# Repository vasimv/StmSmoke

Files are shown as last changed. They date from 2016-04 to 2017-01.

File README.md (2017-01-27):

This is open-source STM32F373C8T6 based vaping mod. Everything is under GPL license (see LICENSE file).

Output power is up to 140 Watts (although you may need a cooler for FETs). 

Schematics and PCB gerber files in the PCB subdirectory. Soon there will be another PCB variant (with
the coil inductor, which stabilizes output power and up to 10000 temperature measures per second). It
is very recommended to use 4-layers PCB with ground plane filled in the middle (otherwise you may get
crosstalk to touch sensors).

The screen is 128x64 OLED 0.96" screen ($4 or so on aliexpress).

Other directories is Ecliplse Mars + GCC/ARM project. There is a lot of crap generated by
STM32CubeMX, main files is:

 include/smoke.h (important stuff, check before compile!)
 src/smoke.c (main code)

The project uses the u8glib library to interface with the screen ( https://github.com/olikraus/u8glib ).

Note, new version uses FDV304P p-fet as additional output MOSFET driver and inverted PWM output, will not
work with older hadrware (comment #define INVERTED_PWM_COIL in smoke.h)!

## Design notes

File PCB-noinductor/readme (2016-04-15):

PCB gerber files. Non-mirrored, non-inverted!

Schematics in the StmSmoke.png file.

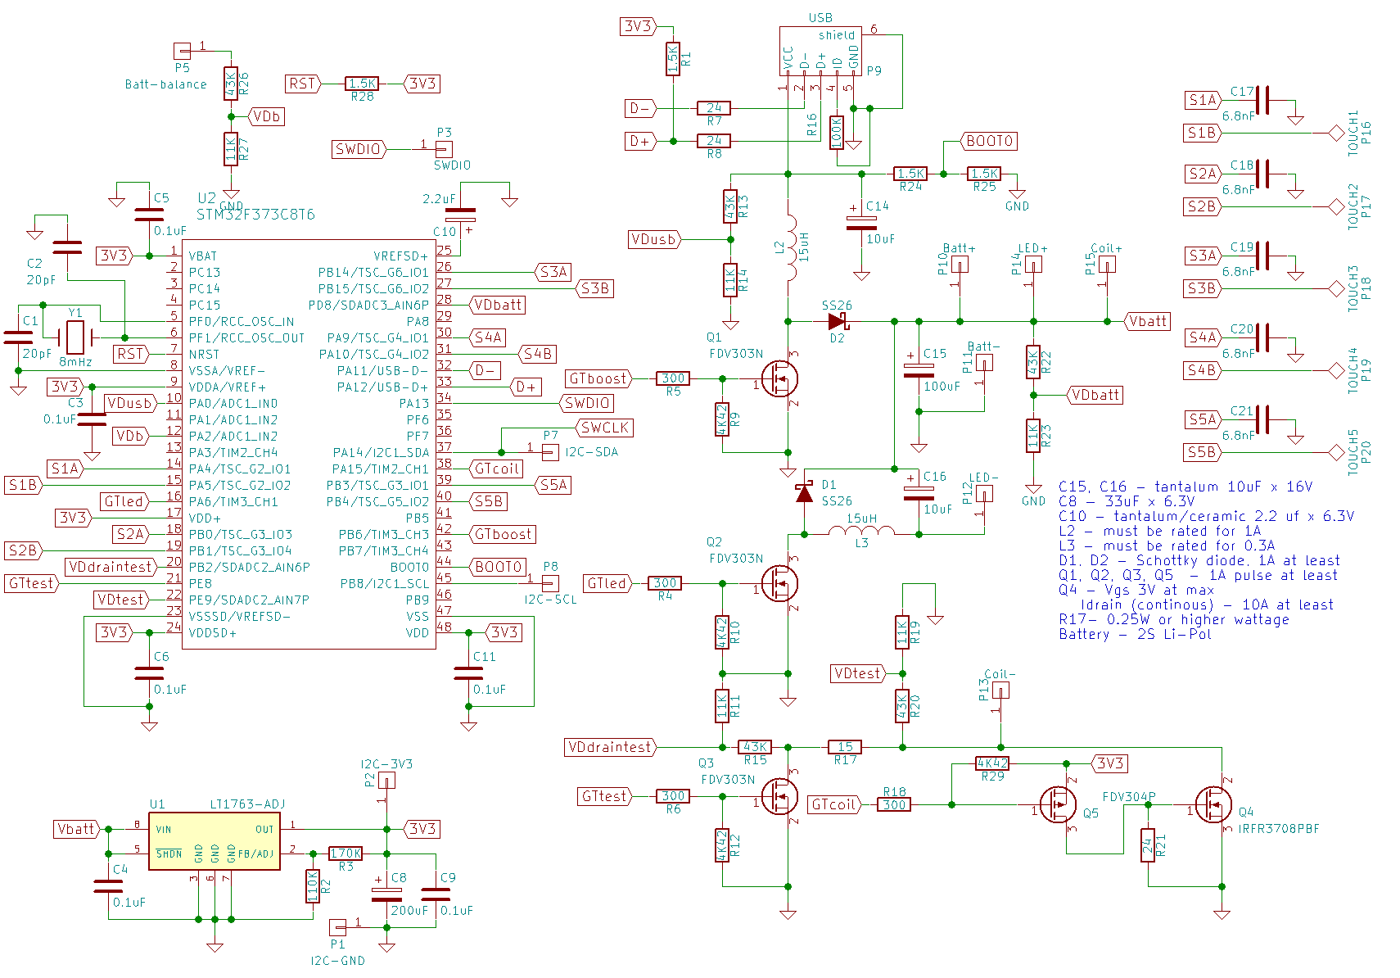
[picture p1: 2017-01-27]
PCB-noinductor/StmSmoke.png

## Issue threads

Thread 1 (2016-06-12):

18650 support

zabbal, 2016-06-12:
Looks neat. Would it be possible to add support for common 18650 li-ion cells? Not necessary with usb charging but just as a power source.

vasimv, 2016-06-12:
Well, it'll work with common cells. You just need series of two (and middle wire to the "batt-balance" port).   Although charging time may be quite long for large capacity batteries (10+ hours for 2000 mAh).

Closed 2016-06-12.

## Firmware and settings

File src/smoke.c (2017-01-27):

/* Temperature controller for vaping mod, schematics in Stm-Smoke.sch or Stm-Smoke-Inductor.sch
 *
 *    Copyright (C) 2016  Vasim V.
 *
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
 *    You should have received a copy of the GNU Lesser General Public License
 *    along with this program. */

#include "stm32f3xx_hal.h"
#include "usb_device.h"
#include "usbd_cdc_if.h"
#include <stdio.h>
#include <stdarg.h>
#include <math.h>
#include "u8g_arm.h"

#include "smoke.h"
#include "flash_data.h"

// u8glib stuff
static u8g_t u8g;

#ifdef USB_DEBUG
char usboutbuf[256];

va_list args;
int nlen;

int VCP_write(const void *pBuffer, int size)
{
    if (size > CDC_DATA_HS_OUT_PACKET_SIZE)
    {
        int offset;
        for (offset = 0; offset < size; offset++)
        {
            int todo = MIN(CDC_DATA_HS_OUT_PACKET_SIZE,
                           size - offset);
            int done = VCP_write(((char *)pBuffer) + offset, todo);
            if (done != todo)
                return offset + done;
        }

        return size;
    }

    USBD_CDC_HandleTypeDef *pCDC =
            (USBD_CDC_HandleTypeDef *)hUsbDeviceFS.pClassData;
    // XXX - set timeout?
    while(pCDC->TxState) {  HAL_Delay(10); } //Wait for previous transfer

    USBD_CDC_SetTxBuffer(&hUsbDeviceFS, (uint8_t *)pBuffer, size);
    if (USBD_CDC_TransmitPacket(&hUsbDeviceFS) != USBD_OK)
        return 0;
    return size;
}

void debug(char *fmt, ...) {
	   // Check if we're really connected
	   if (hUsbDeviceFS.dev_state != USBD_STATE_CONFIGURED)
		   return;
	   va_start(args, fmt);
	   nlen = vsnprintf(usboutbuf, sizeof(usboutbuf), fmt, args);
	   va_end(args);
	   // CDC_Transmit_FS((uint8_t *) usboutbuf, nlen);
	   VCP_write(usboutbuf, nlen);
}
#else
void debug(char *fmt, ...) {
}
#endif

void Init_Screen() {
#if defined(SSD1306_128_64)
	u8g_InitComFn(&u8g, &u8g_dev_ssd1306_128x64_i2c, u8g_com_hw_i2c_fn);
#endif
}

// Coil resistance
float rcoil;

// Coil resistance at 30C
float rcoilzero = 999;

// Locked coil resistance at 25C (don't use if zero)
float rcoillock = 0.0;

// CONF - Minimum and maximum coil resistances
float rmincoil = 0.2;
float rmaxcoil = 6.0;

// Battery voltage, updated in measure_int()
float vmainv;
// Voltage on drain of test FET while testing, updated in measure_int()
float vcheck;
// Voltage on coil while testing, updated in measure_int()
float coilv;
int16_t vmainv_readout = 0;
int16_t vcheck_readout = 0;
int16_t coilv_readout = 0;

// ADC DMA array
int16_t adcdata[5];

// CONF - Temperature limit (in celsius)
float tcut = 230.0;

// CONF - Power limit (in watts)
float pcut = 1.0;

// CONF - Coil regulator mode, 0 - temperature control (tcut), 1 - power limiting (pcut)
uint32_t coilmode = 0;

// Chip temprature (averaged from few readings)
float tchip;

// Chip temperature at wake-up (treating like it is outside temperature)
float tair = -100;

// Coil temperature
float tcoil;

// CONF - coil material type, 0 - Titan
uint32_t coiltype = 0;

// Temperature/resistance koefficient (Titan, SS316L, SS304, NiFe30, Nickel, Kanthal D)
float rtchange[] = {0.003525, 0.000879, 0.001016, 0.0032, 0.006, 0.0001};

// VDDA calculated voltage
float vdda;

// VBAT voltage
float vbat;

// USB voltage
float vusb;

// First cell voltage (2S balance pin)
float vbalance;

// PWM output
float output;

// Alert condition (shouldn't fire coil)
uint8_t alert;

// Coil heat time/flag (in milliseconds), if 0 - should be turned off
uint32_t coilheat;

// CONF - Slow start time (rising output power from 1/10 to maximum during this time), in milliseconds
uint32_t slowheat = 600;

// CONF - lock for plus/minus keys (will able to update through menu only)
uint32_t changekeylock = 0;

// Light is on flag
uint8_t lighton;

// CONF - Sleep timer (if COIL button wasn't pressed)
uint32_t sleeptime = 60;

// CONF - slowcharge mode (less than 100 mA for small batteries)
uint32_t slowcharge = 1;

// CONF - Maximum charge voltage (lower is recommended if no secondary battery checker)
float maxcharge = 8.2;

// While in recharging - boost PWM output
uint8_t charging = 0;

// CONF - Voltage divider ratio (43K/11K - 0.2037, 44K/11K - 0.2)
float dividerratio = 0.2;

// CONF - Coil PID regulator variables
float pidp = 10.0;
float pidi = 0.2;
float pidd = 2.0;

// Main loop cycle count
uint32_t loopcycle = 0;

// HAL_GetTick value after last wake up
uint32_t lastawake;

// We're checking TSC buttons (have to delay SDADC measure as this make crosstalk of some sort)
uint8_t doingtsc = 0;

// Buttons indexes
#define I_BCOIL 0
#define I_BPLUS 1
#define I_BMINUS 2
#define I_BMENU 3

#if NBUTTONS == 5
#define I_BLIGHT 4
#endif

// Buttons calibration (searching for minimal sensor value for specified millseconds)
int buttonscalib;

// TSC Spread Spectrum (for less crosstalks to SDADC;
int tscspread = 1;

// Touch sensor buttons stuff
uint8_t sw_check[NBUTTONS];
uint8_t sbuttons[NBUTTONS];
uint16_t tmpbuttons[NBUTTONS];
uint16_t zerobuttons[NBUTTONS];
uint32_t idlebuttons[NBUTTONS];

// Processed buttons flags
int pbuttons[NBUTTONS];

// UI Control flags
// We're in menu (+/- - navigate, coil - change, menu - exit)
uint8_t inmenu;
// We're in menu, updating a value (+/- - change, coil - save, menu - exit without save)
uint8_t inupdate;
// We're in sleep mode (to unlock - press +, then -, then menu in one second)
uint8_t insleep;
// Need flash memory update (milliseconds from last configuration change)
uint32_t needupdate = 0;
// Have to wait until the  button is released (after wakeup, for example)
uint8_t lockuntilrelease = 255;

// Number of measures made
uint32_t measures = 0;

#ifdef USB_DEBUG
void Stop_USB() {
	USBD_Stop(&hUsbDeviceFS);
	USBD_DeInit(&hUsbDeviceFS);
} // Stop_USB

void Start_USB() {
	MX_USB_DEVICE_Init();
}
#endif

// Set up duty cycle on a timer
void PWM_Timer_Set(TIM_HandleTypeDef *phtim, uint32_t channel, uint32_t pulse) {
	TIM_OC_InitTypeDef sConfigOC;

	sConfigOC.OCMode = TIM_OCMODE_PWM1;
	sConfigOC.Pulse = pulse;
	sConfigOC.OCPolarity = TIM_OCPOLARITY_HIGH;
#ifdef INVERTED_PWM_COIL
	if (phtim == &htim2)
		sConfigOC.OCPolarity = TIM_OCPOLARITY_LOW;
#endif
	sConfigOC.OCFastMode = TIM_OCFAST_DISABLE;
	HAL_TIM_PWM_ConfigChannel(phtim, &sConfigOC, channel);
	HAL_TIM_PWM_Start(phtim, channel);
} // PWM_Timer_Set

void Stop_PWM() {
	charging = 0;
	HAL_TIM_Base_Stop(&htim2);
	HAL_TIM_Base_DeInit(&htim2);
	HAL_TIM_Base_Stop(&htim3);
	HAL_TIM_Base_DeInit(&htim3);
} // Stop_PWM

// Set-up coil and secondary PWMs
void Start_PWM() {
	MX_TIM2_Init();
	htim2.Instance = TIM2;
	htim2.Init.Prescaler = 0;
	htim2.Init.CounterMode = TIM_COUNTERMODE_UP;
	htim2.Init.Period = (PWM_COIL_PERIOD - 1);
	htim2.Init.ClockDivision = TIM_CLOCKDIVISION_DIV1;
	HAL_TIM_Base_Init(&htim2);
	PWM_Timer_Set(&htim2, TIM_CHANNEL_1, 0);

	MX_TIM3_Init();
	PWM_Timer_Set(&htim3, TIM_CHANNEL_1, 0);
	charging = 0;
	lighton = 0;
	PWM_Timer_Set(&htim3, TIM_CHANNEL_3, 0);
} // Start_PWM

// Stop PWM output on coil temporarily
void Stop_Coil() {
	TIM2->CR1 &= ~ TIM_CR1_ARPE;
	TIM2->CCR1 = 0;
} // Stop_Coil

// Restart PWM output on coil FET
void Start_Coil() {
	uint32_t timout;

	if (alert) {
		Stop_Coil();
		return;
	}
	timout = trunc(output);
	if (timout >= PWM_COIL_PERIOD)
		timout = PWM_COIL_PERIOD - 1;
	TIM2->CCR1 = timout;
	TIM2->CR1 |= TIM_CR1_ARPE;
} // Start_Coil

// Reset coil variables/timers
void Reset_Coil() {
	coilheat = 0;
	output = 0.0;
	Stop_Coil();
	if (rcoillock > 0.01) {
		rcoilzero = rcoillock;
		tair = 25;
	}
} // Reset_Coil

// Lock coil resetistance
void Lock_Coil() {
	rcoillock = rcoil;
	rcoilzero = rcoil;
	tair = 25;
} // Lock_Coil

// Close test FET (non-inductor)
void Stop_FET() {
#ifndef INDUCTOR_BASED
	HAL_GPIO_WritePin(GPIOE, GPIO_PIN_8, GPIO_PIN_RESET);
#endif
} // Stop_FET

// Stops GPIO, I2C, TSC stuff
void Stop_Periph() {
	HAL_I2C_DeInit(&hi2c1);
	HAL_TSC_DeInit(&htsc);
} // Stop_GPIO

// Configures GPIO stuff
void Start_Periph() {
	MX_GPIO_Init();
	MX_I2C1_Init();
	MX_TSC_Init();
	MX_RTC_Init();
} // Start_GPIO

#ifdef BURST_DEBUG_DATA
// Collecting data to print out through usb after run
float datacollect[1024];
unsigned int pos = 0;
uint32_t lastcollect = 0;

void Collect_Data(float data) {
	lastcollect = HAL_GetTick();

	datacollect[pos] = data;
	pos++;
	if (pos >= (sizeof(datacollect) / sizeof(datacollect[0])))
		pos = 0;
} // Collect_Data

void Check_Dump_Data(unsigned int linesize) {
	unsigned int i, j;

	if ((pos > 0) && (HAL_GetTick() - lastcollect) > 10000) {
		debug("pos: %f\n", pos);
		j = 0;

		for (i = 0; i < pos; i++) {
			debug("%f ", datacollect[i]);
			HAL_Delay(10);
			j++;
			if (j >= linesize) {
				debug("\n");
				j = 0;
			}
		}
		pos = 0;
	}
}
#endif

float errsum, lasterr;
float outputlast;

// PID controller for temperature control
void PID_Compute(int maxduty) {
	float error = tcut - tcoil;
    float derr = error - lasterr;

    errsum = errsum + error;
    if (errsum > PWM_COIL_PERIOD)
    	errsum = PWM_COIL_PERIOD;
    if (errsum < PWM_COIL_PERIOD)
    	errsum = PWM_COIL_PERIOD;
    output = pidp * error + pidi * errsum + pidd * derr;
    if (output > maxduty)
    	output = maxduty;
    if (output < 0)
    	output = 0;
    lasterr = error;
} // PID_Compute

// Reset PID controller
void Start_PID() {
	errsum = lasterr = outputlast = 0.0;
	output = 0.0;
	if (!coilmode)
		PID_Compute(slowheat ? (PWM_COIL_PERIOD - 1) / 10 : (PWM_COIL_PERIOD - 1));
} // Reset_PID

// Check failsafes
int Check_Failsafes() {
	alert = 0;
	// USB is connected
#ifndef DISABLE_CHARGING
	if (vusb > 1.0)
		alert = 1;
#endif
	// Coil resistance is weird
	if ((rcoil < rmincoil) || (rcoil > rmaxcoil))
		alert = 1;
	// Too high temperature (wrong coil type set perhaps)
	if (!coilmode && (tcoil > 300))
		alert = 1;
	// Device overheat
	if (tchip > 70.0)
		alert = 1;
	// battery voltage is overlimits
	if ((vmainv < MIN_VOLTAGE) || (vmainv > (MIN_VOLTAGE * 1.5)))
		alert = 1;
	if (vbat < 2.3)
		alert = 1;
	return alert;
} // Check_Failsafes

// Update coil PWM output
void Update_PWM() {
	int dividelimit = 1;

	// Slow start'ing to prevent "ooze shooting" and coil burn-up
	if (coilheat < slowheat)
		dividelimit = slowheat / (coilheat + slowheat / 10);
	if (coilmode) {
		// Power limiting
		float curpower = (vmainv * vmainv) / rcoil;

		if (curpower > pcut) {
			output = ((PWM_COIL_PERIOD - 1) * pcut) / curpower;
			// Correct last two in 10 cycles for precise regulation if PWM period is too crude
			if ((PWM_COIL_PERIOD < 1000) && ((coilheat % 10 == 8) || (coilheat % 10 == 9))) {
				int total = trunc(output) * 8;

				output = ((pcut * (PWM_COIL_PERIOD - 1) * 10) / curpower - total) / 2;
			}
		} else
			output = PWM_COIL_PERIOD - 1;
		output = output / dividelimit;
	} else {
		// Temperature control
		PID_Compute((PWM_COIL_PERIOD - 1) / dividelimit);
		// Skip cycle if the PID controller did overheat
		if ((tcoil - tcut) > 2)
			output = 0;
	}
#ifdef BURST_DEBUG_DATA
	Collect_Data(vmainv);
	Collect_Data(coilv);
	Collect_Data(rcoil);
	Collect_Data(coilheat);
	Collect_Data(output);
#endif
	Start_Coil();
} // Update_PWM

// Make measures and update output PWM
void measure_int() {
#ifdef INDUCTOR_BASED
	// We use non-stop DMA conversion when have inductor+shunt
#else
	// We need to turn off coil to take measure
	uint32_t chan;

#ifndef CALIBRATE_SPREAD
	// Skip cycles while TSC is running (too much interference)
	if (doingtsc)
		return;
#endif
	// Turn off coil and open test FET
	Stop_Coil();
	HAL_GPIO_WritePin(GPIOE, GPIO_PIN_8, GPIO_PIN_SET);
#if FET_SWITCH_DELAY > 0
	for (int i = 0; i < FET_SWITCH_DELAY; i++);
#endif
    // Start SDADCs conversion
	HAL_SDADC_InjectedStart(&hsdadc2);
	HAL_SDADC_InjectedStart(&hsdadc3);
	HAL_SDADC_InjectedStart(&hsdadc1);
	// Wait for all SDADCs to finish
	while ((HAL_SDADC_PollForInjectedConversion(&hsdadc1, 0) == HAL_TIMEOUT)
			|| (HAL_SDADC_PollForInjectedConversion(&hsdadc2, 0) == HAL_TIMEOUT)
			|| (HAL_SDADC_PollForInjectedConversion(&hsdadc3, 0) == HAL_TIMEOUT));
	// Close test FET
	HAL_GPIO_WritePin(GPIOE, GPIO_PIN_8, GPIO_PIN_RESET);
    // Restart coil
	if (coilheat)
		Start_Coil();

    // Weird HAL functions returns uint32_t while it is signed int16 actually
	coilv_readout =  (int16_t) HAL_SDADC_InjectedGetValue(&hsdadc1, &chan);
	vcheck_readout = (int16_t) HAL_SDADC_InjectedGetValue(&hsdadc2, &chan);
	vmainv_readout = (int16_t) HAL_SDADC_InjectedGetValue(&hsdadc3 , &chan);
#endif
    coilv = ((VREF_SDADC / 65536.0) / dividerratio) * (coilv_readout + 32767);
    vcheck = ((VREF_SDADC / 65536.0) / dividerratio) * (vcheck_readout + 32767);
    vmainv = ((VREF_SDADC / 65536.0) / dividerratio) * (vmainv_readout + 32767);
    // Calculate coil resistance, substracting test FET forward voltage
	rcoil = RTEST * ((vmainv - vcheck) / (coilv - vcheck) - 1.0);
	if (((rcoilzero / 2) > rcoil) && (rcoillock < 0.01)) {
		rcoilzero = rcoil;
		tcoil = tair;
	} else
		tcoil = (rcoil / rcoilzero - 1) / rtchange[coiltype] + tair;
	if (coilheat && !Check_Failsafes()) {
		Update_PWM();
		coilheat++;
//		debug("coilv %f, vcheck %f, vmainv %f, rcoil %f, tcoil %f, output %f\n", coilv, vcheck, vmainv, rcoil, tcoil, output);
	}
	measures++;
} // measure_int

// Cyclic array for averaging temperature data
float tdata[16];
unsigned int p_tdata = 0;

void Stop_ADC() {
	HAL_ADC_Stop(&hadc1);
	HAL_ADC_Stop_DMA(&hadc1);
} // Stop_ADC

// Start 12-bit ADC (VDUSB pin, temperature, vrefint, vbat)
void Start_ADC() {
	unsigned int i;

	for (i = 0; i < (sizeof(tdata) / sizeof(tdata[0])); i++)
		tdata[i] = -100;
	HAL_ADC_Start_DMA(&hadc1, (uint32_t*)adcdata, 10);
	HAL_ADC_Start(&hadc1);
} // Start_ADC


// Calculate ADC stuff using internal Vrefint and calibration values
void Calculate_ADC() {
	int32_t t;
	unsigned int i;
	float tmp;

	// Calculate voltages based on calibration values and internal Vref
	vdda = (3.3 * VREFINT_CAL) / adcdata[2];
	vbat = (vdda * adcdata[3]) / 2048;
	vusb = ((adcdata[0] * vdda) / 4096) / dividerratio;
	vbalance = ((adcdata[4] * vdda) / 4096) / dividerratio;
	if (vusb < 1.0)
		vusb = 0.0;
	// Calculate temperature based on calibration values (average last 16 readouts)
	t = (adcdata[1] * VREFINT_CAL) / adcdata[2] - TS_CAL1;
    t =  t * ((110000 - 30000) / (TS_CAL2 - TS_CAL1)) + 30000;
    tmp = t / 1000.0;
    tdata[p_tdata] = tmp;
    p_tdata++;
    if (p_tdata >= (sizeof(tdata) / sizeof(tdata[0])))
    	p_tdata = 0;
    // Fill the array with same value at first run
    if (tdata[p_tdata] < -50)
    	for (i = 0; i < (sizeof(tdata) / sizeof(tdata[0])); i++)
    		tdata[i] = tmp;
    // Calculate average temperature
    tmp = 0.0;
    for (i = 0; i < (sizeof(tdata) / sizeof(tdata[0])); i++)
    	tmp += tdata[i];
    tchip = tmp / (sizeof(tdata) / sizeof(tdata[0]));
    // Set air temperature as first reading of the chip temperature
    // (while it did not heat itself yet)
    if (tair < -50)
    	tair = (tchip - 5);
} // Calculate_ADC

// Set PWM boost timer
void Set_Recharge(unsigned int duty) {
	PWM_Timer_Set(&htim3, TIM_CHANNEL_3, duty);
} // Set_Recharge

// Update PWM boost timer accordingly vmainv to keep current in limits
void Update_Recharge() {
	// We don't have current sensor for the battery, so are using pre-calculated values
	// These values are for 2S LiPo 500 mAh battery (150..250 mA charge current)
	switch ((int) round(vmainv * 10.0)) {
	case 60:
	case 61:
	case 62:
		charging = 12;
		break;
	case 63:
	case 64:
		charging = 13;
		break;
	case 65:
		charging = 14;
		break;
	case 66:
		charging = 15;
		break;
	case 67:
	case 68:
		charging = 16;
		break;
	case 69:
	case 70:
		charging = 17;
		break;
	case 71:
	case 72:
		charging = 18;
		break;
	case 73:
	case 74:
	case 75:
		charging = 19;
		break;
	case 76:
	case 77:
		charging = 20;
		break;
	case 78:
	case 79:
		charging = 21;
		break;
	case 80:
	case 81:
		charging = 22;
		break;
	case 82:
	case 83:
		charging = 23;
	case 84:
	case 85:
	case 86:
		charging = 24;
		break;
	default:
		if (vmainv < 6.0)
			charging = 10;
		else
			charging = 0;
	}
	if (slowcharge && (charging > 0))
		charging = charging - 2;
	Set_Recharge(charging);
} // Update_Recharge

// Recharge battery from USB if possible
void Check_Recharge() {
#ifndef DISABLE_CHARGING
	if (charging) {
#ifdef DISABLE_BALANCE
		if ((vusb < 1.0) || (vmainv >= maxcharge) || (tchip > 70)) {
#else
		if ((vusb < 1.0) || (vmainv >= maxcharge) || (tchip > 70) || ((vbalance > 1.0) && (vbalance < 5.0) && (vbalance >= (maxcharge / 2.0)))) {
#endif
			// Stop charging process
			charging = 0;
			Set_Recharge(0);
			return;
		}
		Update_Recharge();
	} else {
#ifdef DISABLE_BALANCE
		if ((vusb > 1.0) && (vmainv < (maxcharge - 0.2))) {
#else
		if ((vusb > 1.0) && (vmainv < (maxcharge - 0.2)) && ((vbalance < 1.0) || (vbalance > 5.0) || (vbalance < ((maxcharge - 0.5) / 2.0)))) {
#endif
			// Start charging process
			Update_Recharge();
		}
	}
#endif
} // Recharge

int8_t buttons_phase = 0;

// Calibrate touch sensors
void Calibrate_Touch() {
	unsigned int i;

	// Calibrate buttons for 200 milliseconds
	buttonscalib = 200;
	for (i = 0; i < NBUTTONS; i++)
		zerobuttons[i] = 65535;
} //

// Reset buttons state (init/wakeup)
void Reset_Buttons() {
	unsigned int i;

	buttons_phase = 0;
	lockuntilrelease = 255;
	inmenu = 0;
	insleep = 0;
	inupdate = 0;
	for (i = 0; i < NBUTTONS; i++) {
		sbuttons[i] = 0;
		idlebuttons[i] = 0;
		sw_check[i] = 0;
		tmpbuttons[i] = 65535;
		pbuttons[i] = 0;
	}
} // Reset_Buttons

// Clear buttons pressed status (after coil fire)
void Clear_Buttons() {
	unsigned int i;

	for (i = 0; i < NBUTTONS; i++) {
		idlebuttons[i] = 0;
		sbuttons[i] = 0;
		pbuttons[i] = 0;
		sw_check[i] = 0;
	}
} // Clear buttons

// Check if button is "pushed"
int Push_Check(unsigned int button) {
 return tmpbuttons[button] < zerobuttons[button];
} // Push_Check

uint32_t lasttick;

// Debounce buttons
void debounce_buttons() {
	unsigned int i;
	int press;
	uint32_t curtick;
	int ticksdiff;

	curtick = HAL_GetTick();
	ticksdiff = curtick - lasttick;
	lasttick = curtick;

	for (i = 0; i < NBUTTONS; i++) {
		press = Push_Check(i);
		if (sbuttons[i] != press) {
			if (sw_check[i] > BUTTONS_DEBOUNCE) {
				sw_check[i] = 0;
				sbuttons[i] = press;
				idlebuttons[i] = 0;
			} else {
				sw_check[i] += ticksdiff;
				idlebuttons[i] += ticksdiff;
			}

		} else {
			sw_check[i] = 0;
			idlebuttons[i] += ticksdiff;
		}
	}
} // debounce_buttons
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
void loop() {
	loopcycle++;

#ifndef DISABLE_SLEEP
	if (idlebuttons[I_BCOIL] > (sleeptime * 1000)) {
		// Can't go into sleep while charging
		if (!charging) {
			debug("Entering sleep\n");
			insleep = 1;
			Prepare_Sleep();
			do {
				Minimal_Sleep();

				HAL_PWR_EnterSTOPMode(PWR_LOWPOWERREGULATOR_ON, PWR_STOPENTRY_WFI);
				// HAL_PWR_EnterSLEEPMode(PWR_MAINREGULATOR_ON, PWR_SLEEPENTRY_WFI);

				Minimal_Unsleep();
			} while (!Wakeup_Check());
			Finish_Unsleep();
			insleep = 0;
		} else {
			// Just turn off screen if charging, turn on back when MENU is pressed
			debug("Turning off screen (%ld %ld)\n", idlebuttons[I_BCOIL], sleeptime);
			Reset_Coil();
			Stop_FET();
			u8g_SleepOn(&u8g);
			while(Just_Pushed(I_BMENU) == 0)
				HAL_Delay(10);
			u8g_SleepOff(&u8g);
			Reset_Buttons();
			lockuntilrelease = I_BMENU;
		}
	}
#endif

#ifdef EXTENDED_DEBUG
	debug("coilv %f (%d), vcheck %f (%d), vmainv %f (%d), output %f\n rcoil %f (%f:%f), vbat %f, vbalance %f, vusb %f, measures %u\n",
			coilv, coilv_readout, vcheck, vcheck_readout, vmainv, vmainv_readout, output,
			rcoil, tcoil, rcoilzero, vbat, vbalance, vusb, measures);
	debug("buttons: %d %d %d %d (%d)\n", tmpbuttons[0], tmpbuttons[1], tmpbuttons[2], tmpbuttons[3], coilheat);
//	debug("adc: %d %d %d %d %d %d %d\n", adcdata[0], adcdata[1], adcdata[2], adcdata[3],
//			VREFINT_CAL, TS_CAL1, TS_CAL2);
#endif

#ifdef BURST_DEBUG_DATA
	Check_Dump_Data(5);
#endif

	Process_Buttons();

	tcoil_show = tcoil;
	vmainv_show = vmainv;
	rcoil_show = rcoil;
	output_show = output;
	tchip_show = tchip;
	if (loopcycle > 1) {
		u8g_FirstPage(&u8g);
		do {
			if (inmenu)
				Draw_Menu();
			else if (inupdate)
				Draw_Item();
			else
				Draw_Main();
		} while (u8g_NextPage(&u8g));
	}

    HAL_Delay(50);
}

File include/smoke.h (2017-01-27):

/* Temperature controller for vaping mod, schematics in Stm-Smoke.sch or Stm-Smoke-Inductor.sch
 *
 *    Copyright (C) 2016  Vasim V.
 *
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
 *    You should have received a copy of the GNU Lesser General Public License
 *    along with this program. */

// Dump debug information through USB virtual com-port (may create weird effects, DON'T USE if you don't need)
//#define USB_DEBUG

#ifdef USB_DEBUG
// Disable USB charging (for test purposes)
#define DISABLE_CHARGING

// Disable Sleep mode (for test purposes)
#define DISABLE_SLEEP

// Extended debug (very noisy and may hung up)
#define EXTENDED_DEBUG

// Collecting coil data into internal memory to dump it after 10 seconds (doesn't work actually)
// #define BURST_DEBUG_DATA
#endif

// Find best value for spread spectrum (lowest crosstalk to SDADC from TSC)
#define CALIBRATE_SPREAD

// 48 MHz clocking
#define PWM_PERIOD_1MHZ 48
#define PWM_PERIOD_100KHZ 480
#define PWM_PERIOD_10KHZ 4800

// Inverted output of coil's PWM (0 to heat), in case if you have inverted PWM driver with P-FET
#define INVERTED_PWM_COIL

// Disable balance check (if not connected)
// #define DISABLE_BALANCE

// Use inductor-based schematics (double check or it'll fry your board!)
// Inductor - TIM2_CH1 - Coil FET with gate driver, TIM3_CH3 - USB boost FET, PC13 - LED/with resistor
//  ADC1_IN0 - USB, ADC1_IN2 - 2S balance pin, SDADC1_AIN7P - Current sense, SDADC3_AIN6P - Battery
//  Only 4 sensor buttons
//
// Without inductor - TIM2_CH1 - Coil FET without driver, TIM3_CH1 - LED/with inductor, TIM3_CH3 - USB boost FET, PE8 - Resistance test FET,
//  ADC1_IN0 - USB, ADC1_In2 - 2S balance pin, SDADC1_AIN7P - Resistance test, SDADC2_AIN6P - Resistance test FET drain, SDADC3_AIN6P - Battery
//  5 sensor buttons

// #define INDUCTOR_BASED

#ifdef INDUCTOR_BASED
#define NBUTTONS 4
#define PWM_COIL_PERIOD PWM_PERIOD_1MHZ // 1 MHz pwm output, with fast-switching gate driver
#define LED_PC13
#define DISABLE_LIGHT
#else
#define NBUTTONS 5
//#define PWM_COIL_PERIOD PWM_PERIOD_10KHZ // 10 KHz pwm output, without gate driver
#define PWM_COIL_PERIOD PWM_PERIOD_100KHZ // 100 KHz pwm output, with FDV304P P-FET as gate driver
//#define PWM_COIL_PERIOD PWM_PERIOD_1MHZ
#define LED_TIM3CH1
// duty for LED buck regulator (70 mA current with two white LEDs in series)
#define LED_PWM_DUTY 36
#endif

// Swap LIGHT and MENU buttons
#if NBUTTONS == 5
#define SWAP_MENU_LIGHT
#endif

// Disable light button
//#define DISABLE_LIGHT

// Maximum coil heat time (in milliseconds)
#define MAX_COIL_TIME 60000

// Maximum power in variwatt mode, in watts
#define MAX_COIL_POWER 140

// test FET switching delay
#define FET_SWITCH_DELAY 36

// buttons debounce delay (in milliseconds)
#define BUTTONS_DEBOUNCE 100

// touch sensors threshold koefficient (from maximum at calibration)
#define BUTTONS_THRESHOLD 0.9

// buttons repeat delay (in milliseconds)
#define BUTTONS_REPEAT_DELAY 500

// Use only +/- to wake up instead +/-/M
#define WAKEUP_ONLY_TWO

// Write configuration to flash after last change (in milliseconds)
#define UPDATE_FLASH_AFTER 30000

// Frequency for measure/pid routine call (without inductor - only 500Hz/1kHz is supported
// as it will heat coil a bit). 200Hz is for debugging
// #define MEASURE_200HZ
#define MEASURE_500HZ
// #define MEASURE_1KHZ
// #define MEASURE_5KHZ
// #define MEASURE_10KHZ

// VREF used for SDADCs (1.8 volts internal)
#define VREF_SDADC 1.8

// Test resistor resistance, in Ohms
#define RTEST 15.0

// Warning (flashing on screen) battery voltage level
#define WARN_VOLTAGE 6.6

// Minimum battery voltage (won't heat coil if less)
#define MIN_VOLTAGE 6.2

// Screen type
// not supported yet - #define SSD1306_96_32
#define SSD1306_128_64

// Defined in main.c
extern SDADC_HandleTypeDef hsdadc1;
extern SDADC_HandleTypeDef hsdadc2;
extern SDADC_HandleTypeDef hsdadc3;
extern TSC_HandleTypeDef htsc;
extern TIM_HandleTypeDef htim2;
extern TIM_HandleTypeDef htim3;
extern TIM_HandleTypeDef htim6;
extern TIM_HandleTypeDef htim7;
extern ADC_HandleTypeDef hadc1;
extern DMA_HandleTypeDef hdma_adc1;
extern I2C_HandleTypeDef hi2c1;
extern TSC_HandleTypeDef htsc;

extern void SystemClock_Config();
extern void MX_GPIO_Init(void);
extern void MX_I2C1_Init(void);
extern void MX_TIM2_Init(void);
extern void MX_TIM3_Init(void);
extern void MX_TSC_Init(void);
extern void MX_RTC_Init(void);

#ifdef USB_DEBUG
#include "usbd_def.h"
// Defined in usb_device.c
extern USBD_HandleTypeDef hUsbDeviceFS;
#endif

extern int tscspread;

// STM32F37x datasheet addresses
//Temperature sensor raw value at 30 degrees C, VDDA=3.3V
#define TS_CAL1 (*((uint16_t *) 0x1FFFF7B8))
//Temperature sensor raw value at 110 degrees C, VDDA=3.3V
#define TS_CAL2 (*((uint16_t *) 0x1FFFF7C2))
//Internal voltage reference raw value at 30 degrees C, VDDA=3.3V
#define VREFINT_CAL (*((uint16_t *) 0x1FFFF7BA))

// Debug output routine (over USB if USB_DEBUG defined)
void debug(char *fmt, ...);
// Initialization (after HAL inits)
void Setup();
// Main loop
void loop();
// Measure/PID interrupt routine
void measure_int();
// 1 kHz low priority interrupt routine (buttons debounce, some checks, etc)
void timer_int();

// How many PWM periods between measures (for the PID controller)
#if defined(MEASURE_200HZ)
#define PID_TIMECHANGE ((double) (240000 / PWM_COIL_PERIOD))
#elif defined(MEASURE_500HZ)
#define PID_TIMECHANGE ((double) (96000 / PWM_COIL_PERIOD))
#elif defined(MEASURE_1KHZ)
#define PID_TIMECHANGE ((double) (48000 / PWM_COIL_PERIOD))
#elif defined(MEASURE_5KHZ)
#define PID_TIMECHANGE ((double) (9600 / PWM_COIL_PERIOD))
#elif defined(MEASURE_10KHZ)
#define PID_TIMECHANGE ((double) (4800 / PWM_COIL_PERIOD))
#endif

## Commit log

2016-04-15 Creating repository
    [StmSmoke-B.Cu.gbr, StmSmoke-B.Mask.gbr, StmSmoke-B.SilkS.gbr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]
2016-04-16 Added buttons auto-calibration
2016-04-16 PID overshoot fix Burst data transfer
    [smoke.c, smoke.h]
2016-04-16 Default PID values
2016-04-20 TSC spread spectrum auto calibration, bold font removal, usb tuning
2016-11-04 Some fixup for TSC
    [smoke.c, smoke.h]
2017-01-27 New version with FDV304P output MOSFET driver.
    [StmSmoke-NPTH.drl]

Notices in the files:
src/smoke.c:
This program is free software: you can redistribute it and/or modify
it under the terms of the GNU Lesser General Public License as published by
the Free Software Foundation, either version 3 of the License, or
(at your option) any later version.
